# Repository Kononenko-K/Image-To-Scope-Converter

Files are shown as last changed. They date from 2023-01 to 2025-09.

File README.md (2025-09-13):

# Image-To-Scope-Converter
Raster oscilloscope image generator from an arbitrary bitmap file.
<br/>
<p align="center">
     
</p>

## Overview
The idea behind this project is based on the fact that rapid signal transitions are almost imperceptible on a CRT. Thus, if we make a signal jump with a very short rise/fall time from point A to point B, there will be no visible trace of movement on the display. Here, I use the MCU's DAC to generate horizontal and vertical scan signals, and an open-drain GPIO output to create the sharpest possible edge by shorting the DAC output to ground (which is not ideal, but the DAC's output impedance is relatively high anyway). This allows to return the dot on the screen to the zero position when the pixel is white, enabling the display of a raster image on any 2-channel CRT oscilloscope in XY mode without modifying its circuitry for brightness modulation.

## [Hardware](Hardware)
<p align="center">
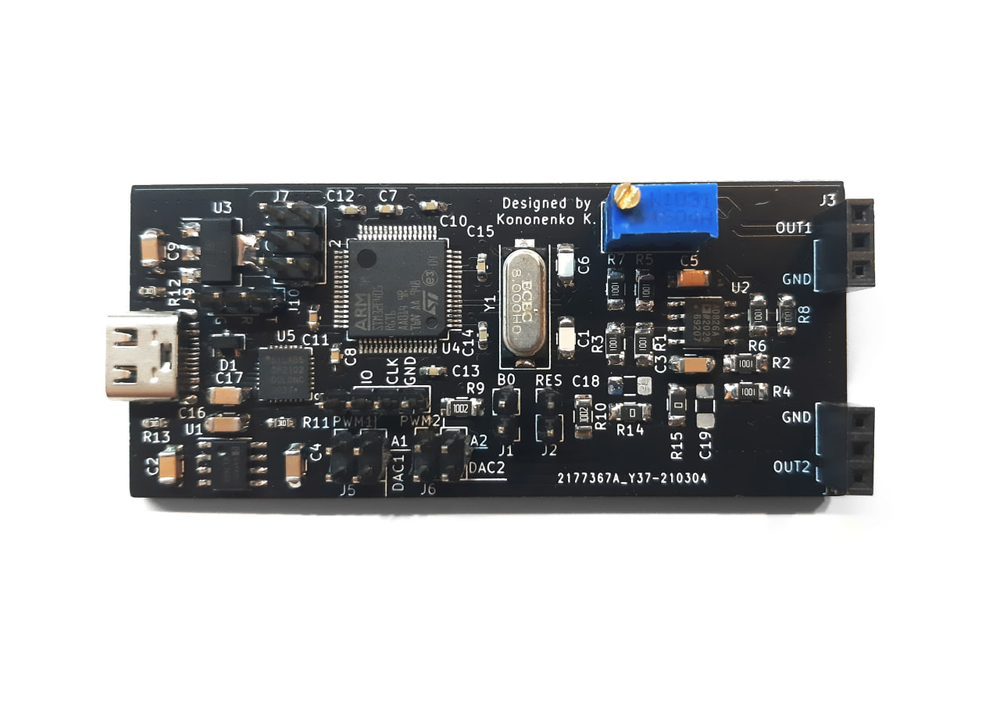
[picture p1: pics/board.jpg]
    
</p>

The board features an STM32F405 series MCU, USB-UART converter, USB Type-C connector, negative voltage generator, and a wideband 2-channel operational amplifier. [KiCad project files](/Hardware/PCB) and [PDF documentation](/Hardware/PCB/project.pdf) are avaliable. For correct operation, DACx and PWMx outputs should both be connected to the corresponding Ax pins.

## [Firmware](Firmware)
The firmware is configured to work with a 1 MBd USART speed, 256×256 image resolution, and adjustable frame rate. The MCU receives an 8192-byte array representing XBM-format images with 1 bit per pixel encoding. The frame rate can be adjusted using the button connected to the PB1 pin. A test image is included in the firmware and can be found in [test_im.h](/Firmware/Core/Src/test_im.h). It is displayed immediately after power-on until another image is loaded via UART.
The project is developed using STM32CubeIDE with HAL.

## [Software](Software)
<p align="center">
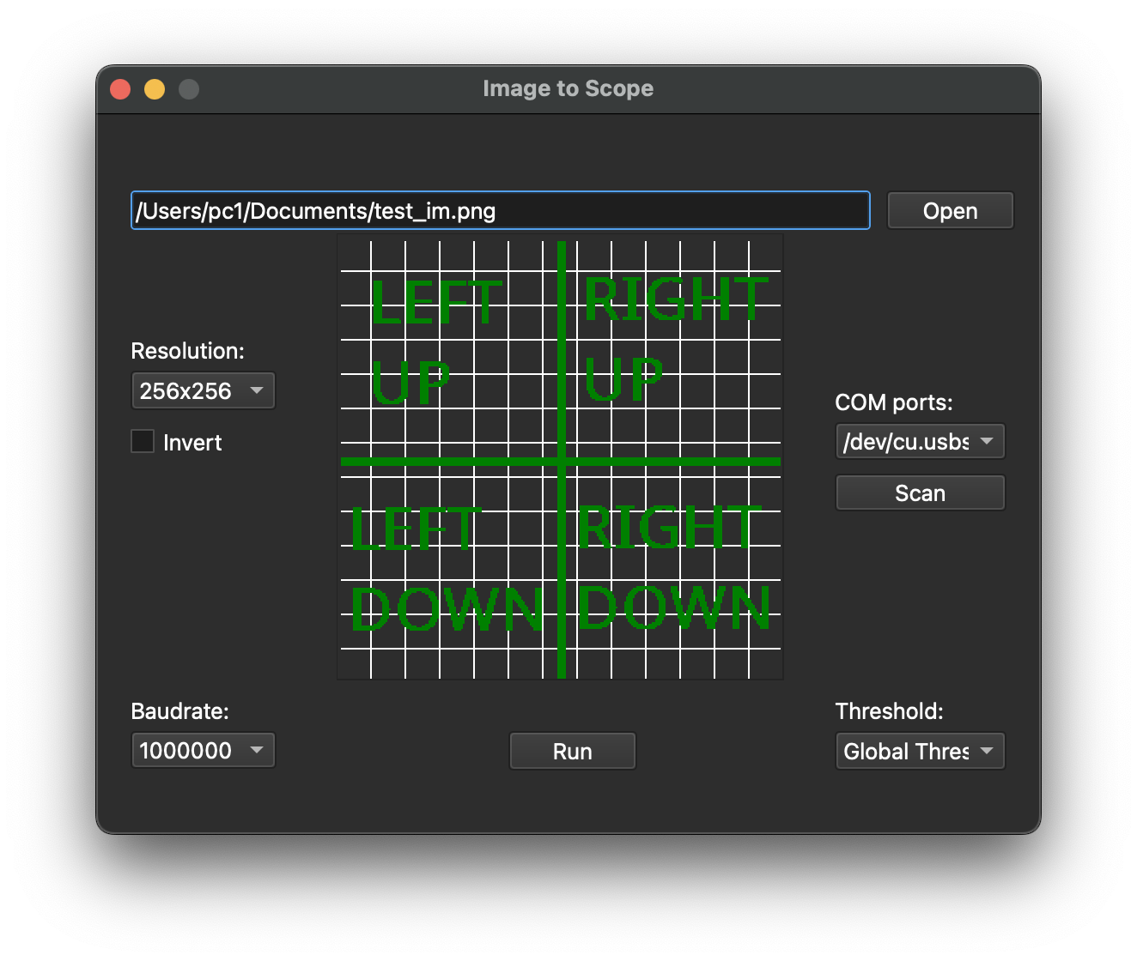
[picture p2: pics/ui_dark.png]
    
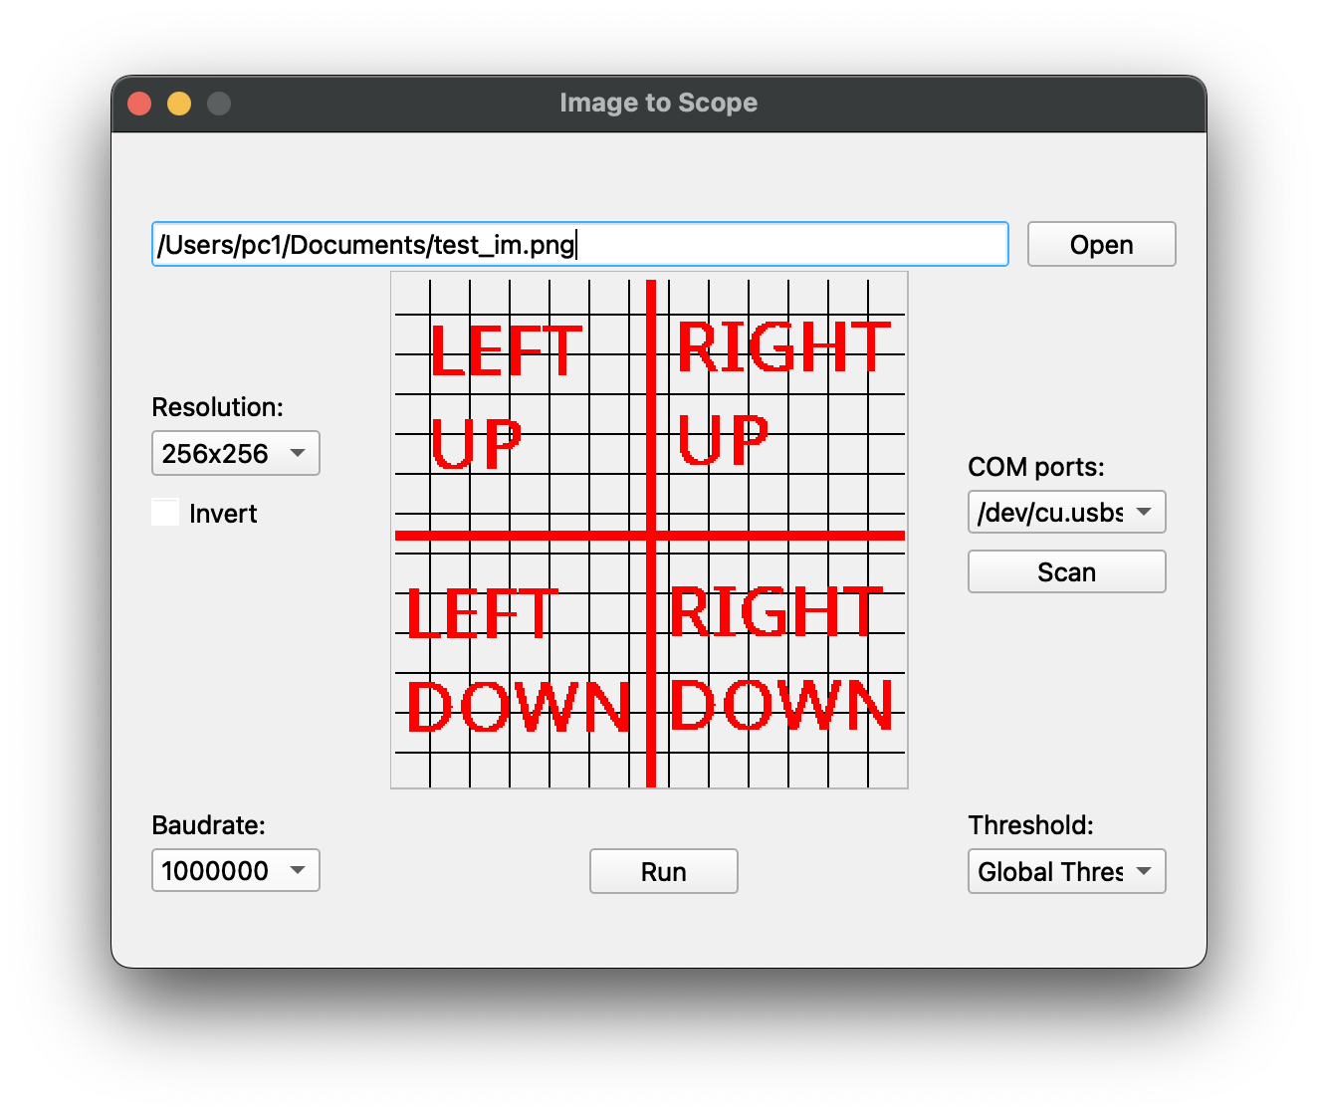
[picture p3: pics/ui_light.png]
    
</p>

I developed a Python PyQt6 script for the project GUI that generates properly formatted data from arbitrary images. Here are the [source code](/Software/ui.py) and [requirements](/Software/requirements.txt).

## [Enclosure](/Hardware/Enclosure)
<p align="center">
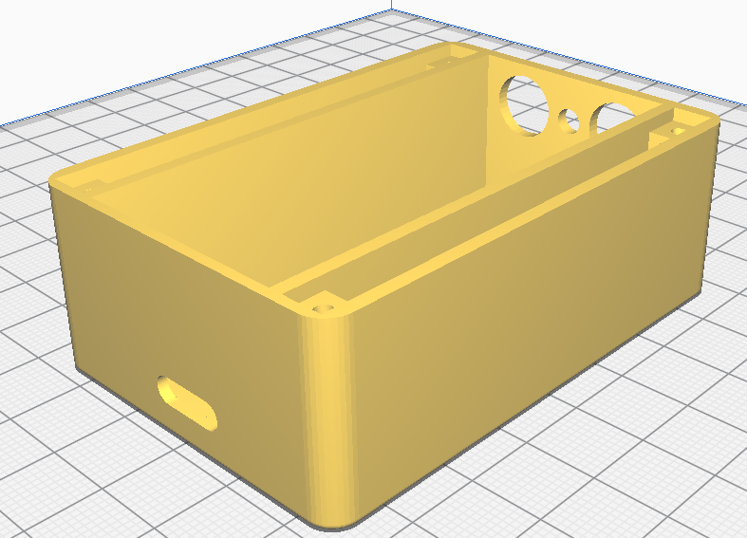
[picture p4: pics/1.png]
    
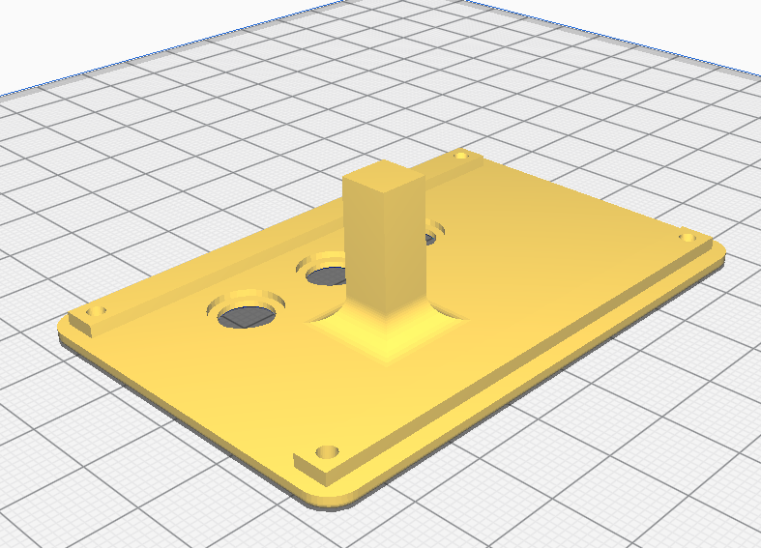
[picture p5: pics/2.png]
    
</p>

STL files for the [case](/Hardware/Enclosure/1.stl) and its [cover](/Hardware/Enclosure/2.stl) for 3D printing.

## License
- The **Software** and **Firmware** in this project are licensed under the [MIT License](/Firmware/LICENSE), with the exception of portions of the firmware code that are copyrighted by STMicroelectronics; such portions are subject to the original licensing terms provided by STMicroelectronics.
- The **Hardware** in this project is licensed under the [CERN Open Hardware Licence Permissive (CERN OHL-P)](/Hardware/LICENSE).

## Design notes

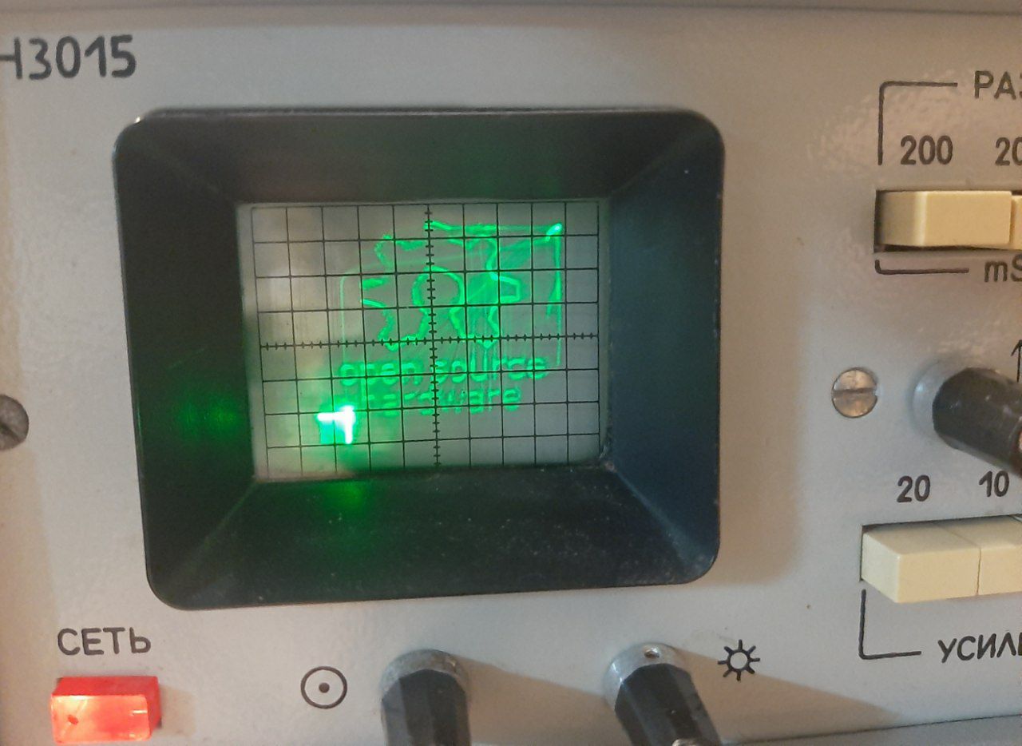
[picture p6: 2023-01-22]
pics/scope.jpg

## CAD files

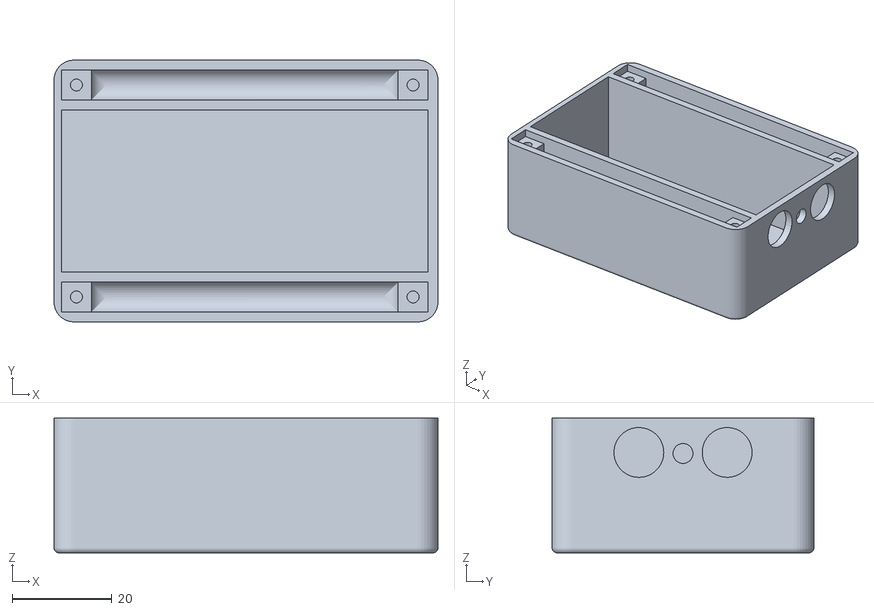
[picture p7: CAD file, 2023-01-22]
Hardware/Enclosure/1.stl
77.0 x 52.5 x 27.0

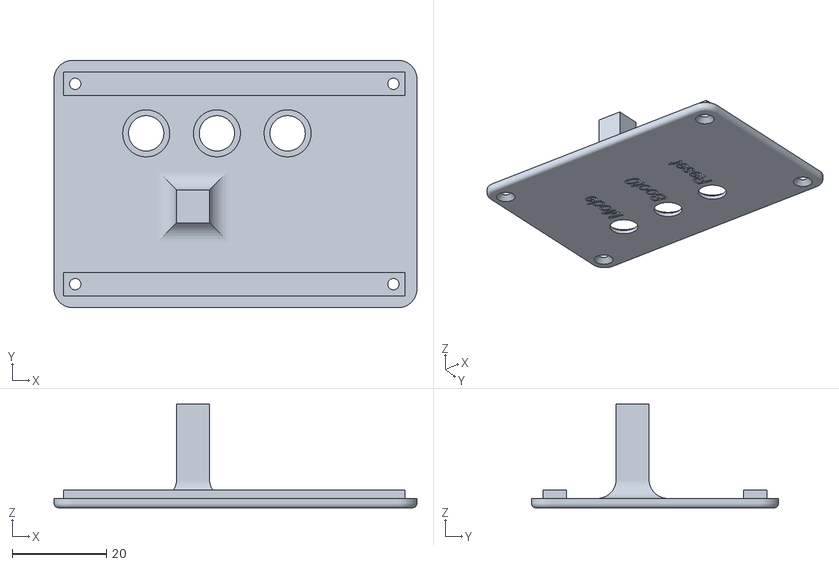
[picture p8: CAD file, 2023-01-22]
Hardware/Enclosure/2.stl
77.0 x 52.5 x 22.0

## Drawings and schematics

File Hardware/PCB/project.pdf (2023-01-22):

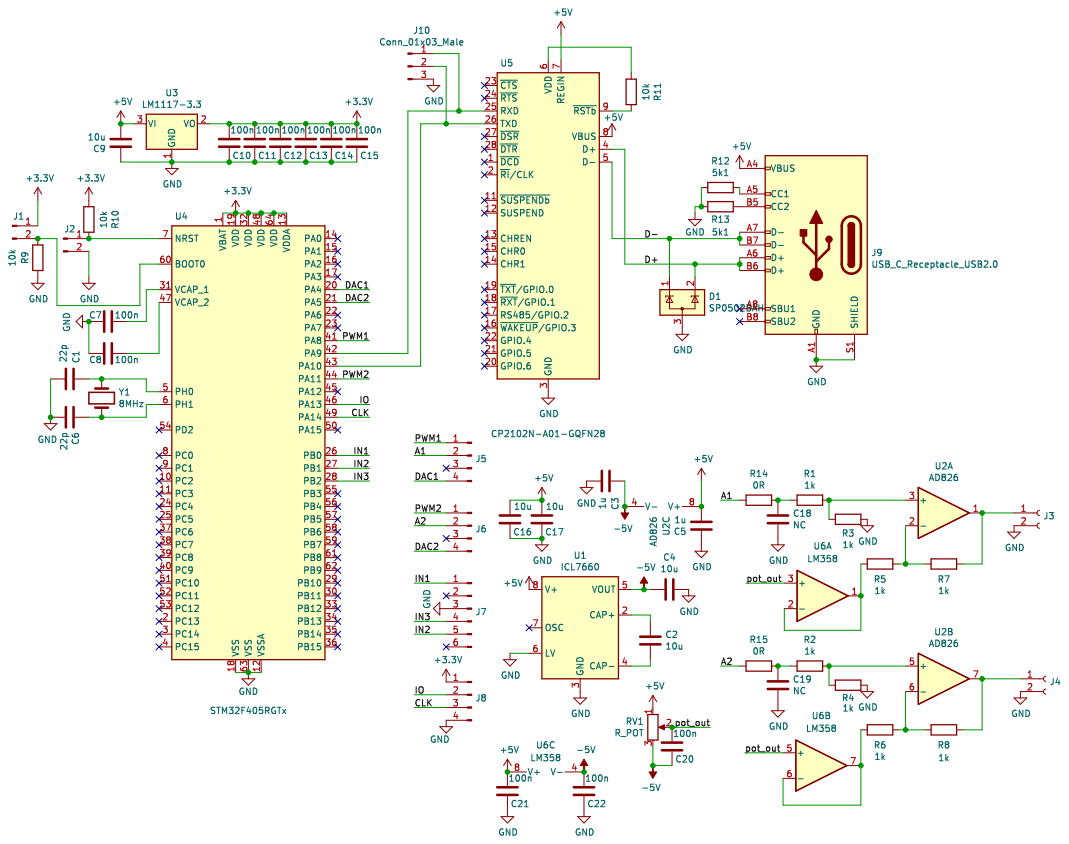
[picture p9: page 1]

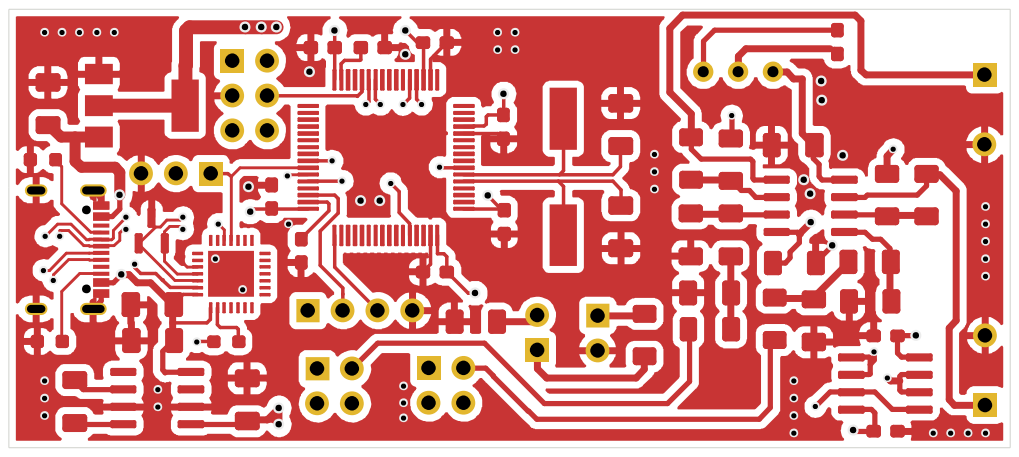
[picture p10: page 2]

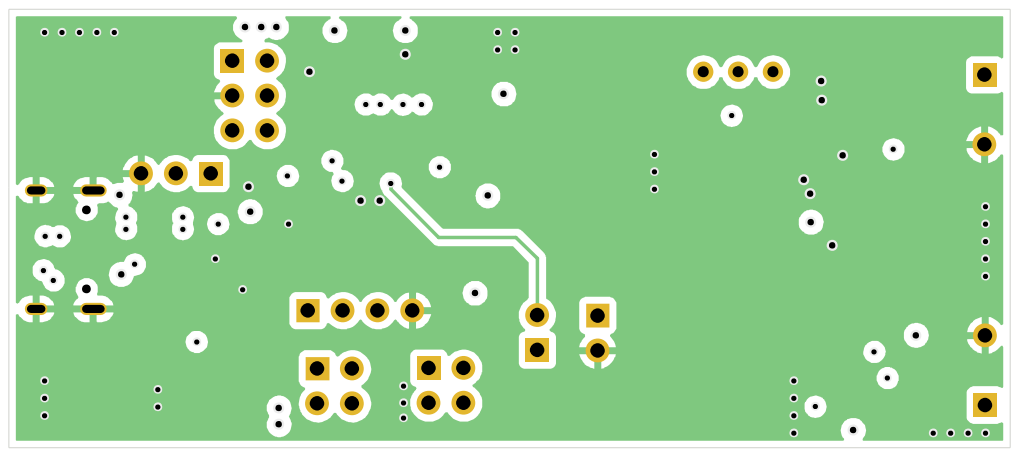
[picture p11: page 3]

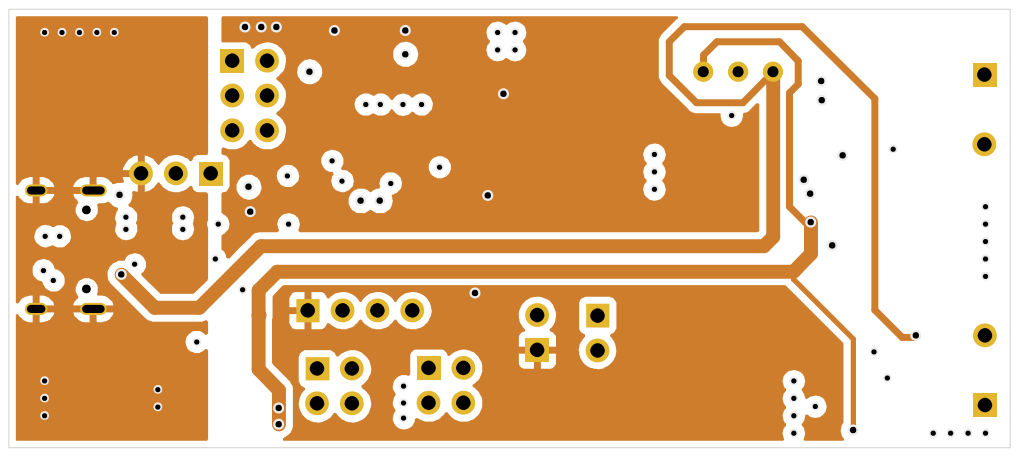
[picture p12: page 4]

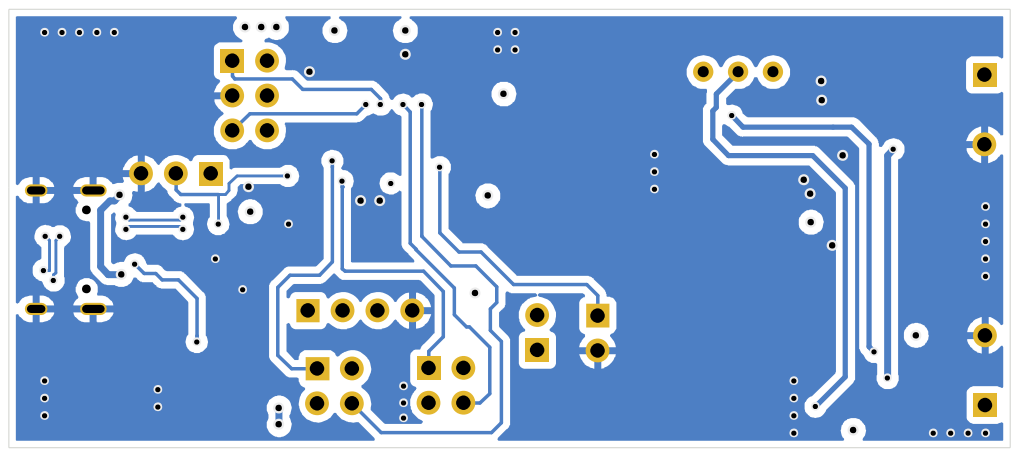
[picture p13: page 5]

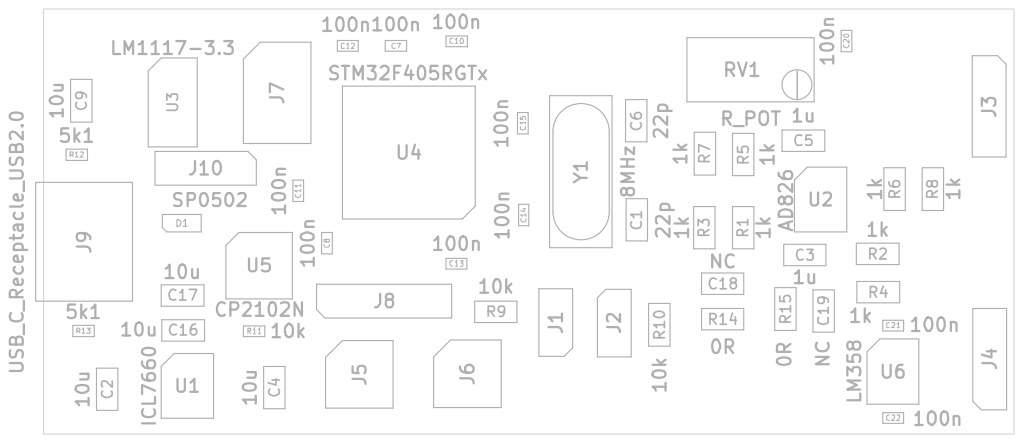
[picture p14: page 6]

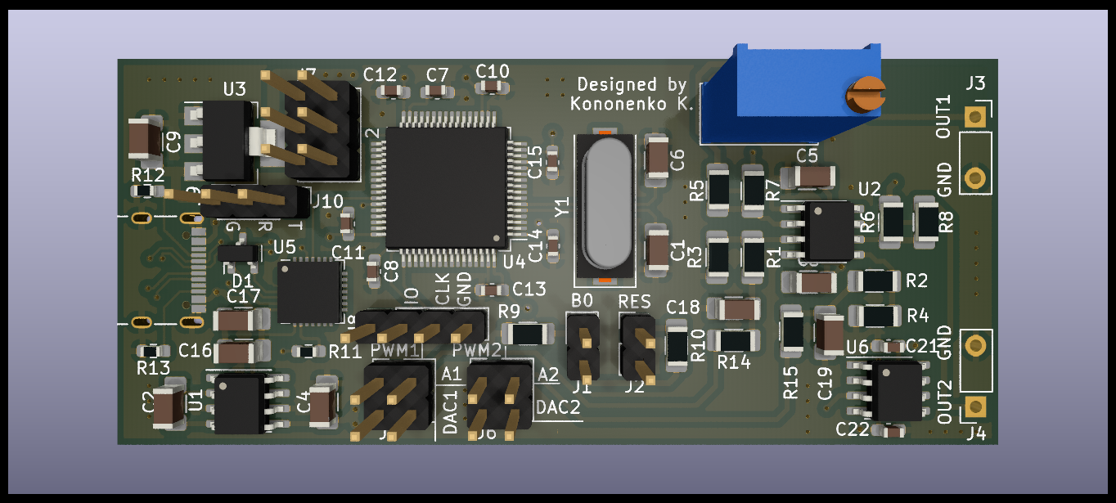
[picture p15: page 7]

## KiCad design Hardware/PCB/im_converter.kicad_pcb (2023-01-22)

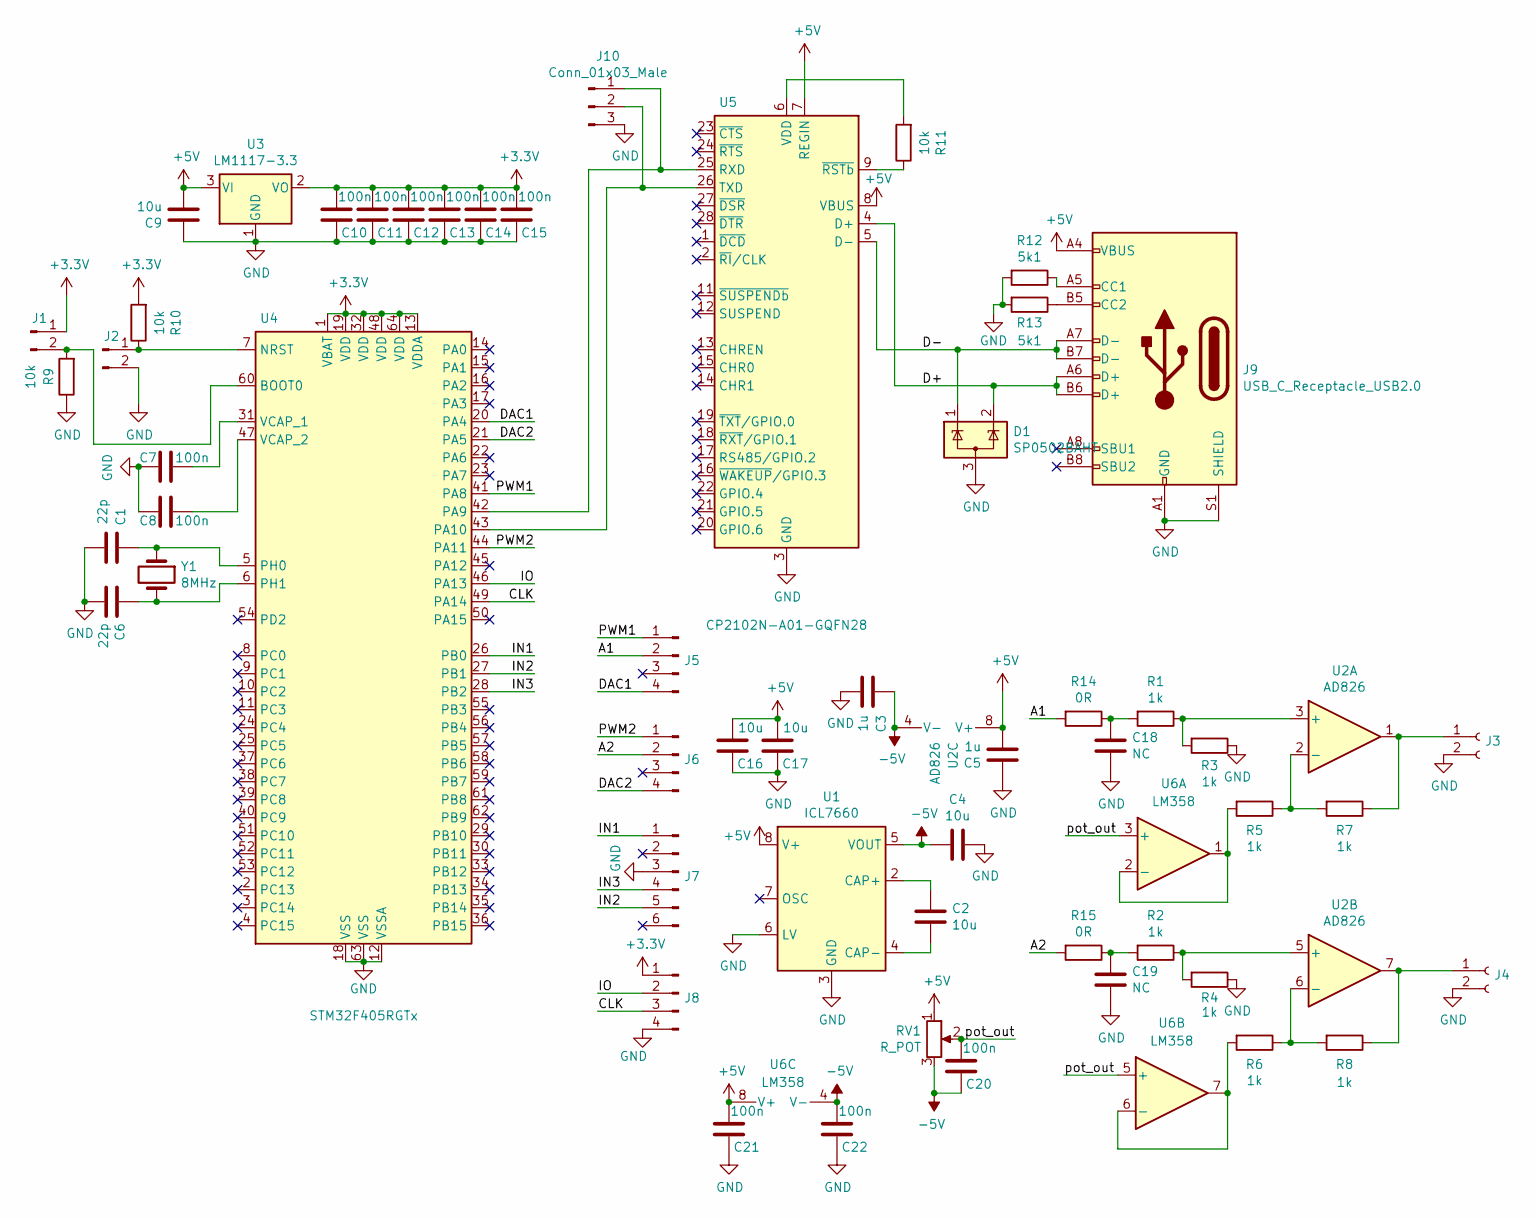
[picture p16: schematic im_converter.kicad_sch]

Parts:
C1, C6: 22p; C_1206_3216Metric_Pad1.33x1.80mm_HandSolder
C2, C4, C9, C16, C17: 10u; C_1206_3216Metric_Pad1.33x1.80mm_HandSolder
C3, C5: 1u; C_1206_3216Metric_Pad1.33x1.80mm_HandSolder
C7, C8, C10, C11, C12, C13, C14, C15, C20, C21, C22: 100n; C_0603_1608Metric_Pad1.08x0.95mm_HandSolder
C18, C19: NC; C_1206_3216Metric_Pad1.33x1.80mm_HandSolder
D1: SP0502BAHT; SOT-23
J1, J2: Conn_01x02_Male; PinHeader_1x02_P2.54mm_Vertical
J3, J4: Conn_01x02_Female; PinSocket_1x03_P2.54mm_Vertical
J5, J6: Conn_01x04_Male; PinHeader_2x02_P2.54mm_Vertical
J7: Conn_01x06_Male; PinHeader_2x03_P2.54mm_Vertical
J8: Conn_01x04_Male; PinHeader_1x04_P2.54mm_Vertical
J9: USB_C_Receptacle_USB2.0; USB_C_Receptacle_Palconn_UTC16-G
J10: Conn_01x03_Male; PinHeader_1x03_P2.54mm_Vertical
R1, R2, R3, R4, R5, R6, R7, R8: 1k; R_1206_3216Metric_Pad1.30x1.75mm_HandSolder
R9, R10: 10k; R_1206_3216Metric_Pad1.30x1.75mm_HandSolder
R11: 10k; R_0603_1608Metric_Pad0.98x0.95mm_HandSolder
R12, R13: 5k1; R_0603_1608Metric_Pad0.98x0.95mm_HandSolder
R14, R15: 0R; R_1206_3216Metric_Pad1.30x1.75mm_HandSolder
RV1: R_POT; Potentiometer_Bourns_3296W_Vertical
U1: ICL7660; SOIC-8_3.9x4.9mm_P1.27mm
U2: AD826; SOIC-8_3.9x4.9mm_P1.27mm
U3: LM1117-3.3; SOT-223-3_TabPin2
U4: STM32F405RGTx; LQFP-64_10x10mm_P0.5mm
U5: CP2102N-A01-GQFN28; QFN-28-1EP_5x5mm_P0.5mm_EP3.35x3.35mm
U6: LM358; SOIC-8_3.9x4.9mm_P1.27mm
Y1: 8MHz; Crystal_SMD_HC49-SD

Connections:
+3V3: C10.2, C11.2, C12.2, C13.2, C14.2, C15.2, J1.1, J8.1, R10.2, U3.2 (VO), U4.1 (VBAT), U4.13 (VDDA), U4.19 (VDD), U4.32 (VDD), U4.48 (VDD), U4.64 (VDD)
+5V: C5.2, C9.2, C16.2, C17.2, C21.2, J9.A4 (VBUS), J9.A9 (VBUS), J9.B4 (VBUS), J9.B9 (VBUS), RV1.1, U1.8 (V+), U2.8 (V+), U3.3 (VI), U5.7 (REGIN), U5.8 (VBUS), U6.8 (V+)
-5V: C3.1, C4.2, C20.1, C22.2, RV1.3, U1.5 (VOUT), U2.4 (V-), U6.4 (V-)
/A1: J5.2, R14.2
/A2: J6.2, R15.2
/CLK: J8.3, U4.49 (PA14)
/D+: D1.2 (K), J9.A6 (D+), J9.B6 (D+), U5.4 (D+)
/D-: D1.1 (K), J9.A7 (D-), J9.B7 (D-), U5.5 (D-)
/DAC1: J5.4, U4.20 (PA4)
/DAC2: J6.4, U4.21 (PA5)
/IN1: J7.1, U4.26 (PB0)
/IN2: J7.5, U4.27 (PB1)
/IN3: J7.4, U4.28 (PB2)
/IO: J8.2, U4.46 (PA13)
/PWM1: J5.1, U4.41 (PA8)
/PWM2: J6.1, U4.44 (PA11)
/pot_out: C20.2, RV1.2, U6.3 (+), U6.5 (+)
GND: C1.2, C3.2, C4.1, C5.1, C6.2, C7.2, C8.2, C9.1, C10.1, C11.1, C12.1, C13.1, C14.1, C15.1, C16.1, C17.1, C18.2, C19.2, C21.1, C22.1, D1.3 (A), J2.2, J3.2, J4.2, J7.3, J8.4, J9.A1 (GND), J9.A12 (GND), J9.B1 (GND), J9.B12 (GND), J9.S1 (SHIELD), J10.3, R3.1, R4.1, R9.1, R12.2, R13.2, U1.3 (GND), U1.6 (LV), U3.1 (GND), U4.12 (VSSA), U4.18 (VSS), U4.63 (VSS), U5.3 (GND), U5.29 (GND)
unnamed: C1.1, U4.5 (PH0), Y1.1
unnamed: C2.1, U1.2 (CAP+)
unnamed: C2.2, U1.4 (CAP-)
unnamed: C6.1, U4.6 (PH1), Y1.2
unnamed: C7.1, U4.31 (VCAP_1)
unnamed: C8.1, U4.47 (VCAP_2)
unnamed: C18.1, R1.2, R14.1
unnamed: C19.1, R2.2, R15.1
unnamed: J1.2, R9.2, U4.60 (BOOT0)
unnamed: J2.1, R10.1, U4.7 (NRST)
unnamed: J3.1, R7.1, U2.1
unnamed: J4.1, R8.1, U2.7
unnamed: J9.A5 (CC1), R12.1
unnamed: J9.B5 (CC2), R13.1
unnamed: J10.1, U4.42 (PA9), U5.25 (RXD)
unnamed: J10.2, U4.43 (PA10), U5.26 (TXD)
unnamed: R1.1, R3.2, U2.3 (+)
unnamed: R2.1, R4.2, U2.5 (+)
unnamed: R5.1, R7.2, U2.2 (-)
unnamed: R5.2, U6.1, U6.2 (-)
unnamed: R6.1, R8.2, U2.6 (-)
unnamed: R6.2, U6.6 (-), U6.7
unnamed: R11.1, U5.9 (~RSTb)
unnamed: R11.2, U5.6 (VDD)

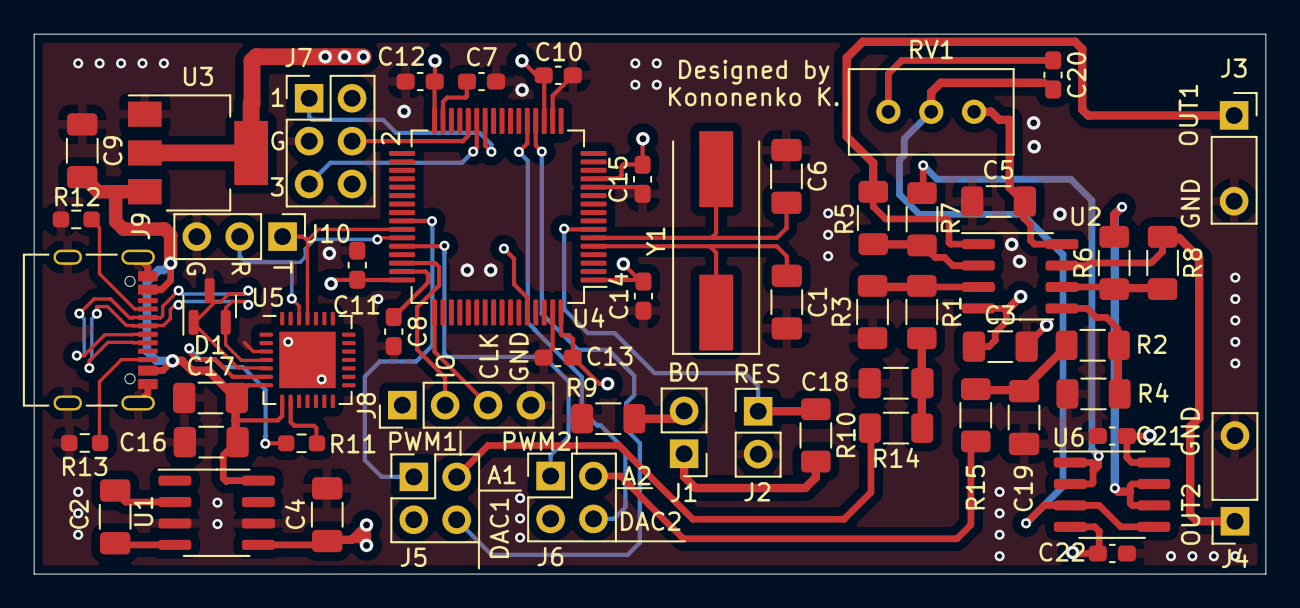
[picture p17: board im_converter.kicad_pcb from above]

Board: 4 copper layers, 73.0 x 32.0 mm, 56 parts (0 on the bottom side), 42 nets.

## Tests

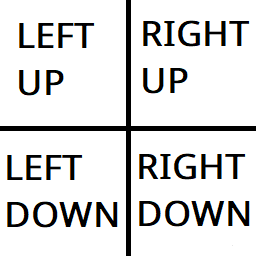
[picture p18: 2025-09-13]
Software/input_pics/test_im.png

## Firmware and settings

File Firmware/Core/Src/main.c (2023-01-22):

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
/* Includes ------------------------------------------------------------------*/
#include "main.h"

/* USER CODE BEGIN Includes */
#include "test_im.h"
/* USER CODE END Includes */

/* USER CODE BEGIN PD */
#define BUFSIZE 8192
#define INIT_PRESC 115
#define DECR_PRESC 15
/* USER CODE END PD */

DAC_HandleTypeDef hdac;

TIM_HandleTypeDef htim1;
TIM_HandleTypeDef htim2;
TIM_HandleTypeDef htim3;

UART_HandleTypeDef huart1;

/* USER CODE BEGIN PV */
//extern static uint8_t test_im[];
uint8_t buff[BUFSIZE] = {0,};
uint8_t v = 0;
uint8_t presc1 = INIT_PRESC;
/* USER CODE END PV */

void SystemClock_Config(void);
static void MX_GPIO_Init(void);
static void MX_TIM1_Init(void);
static void MX_USART1_UART_Init(void);
static void MX_DAC_Init(void);
static void MX_TIM3_Init(void);
static void MX_TIM2_Init(void);
/**
  * @brief  The application entry point.
  * @retval int
  */
int main(void)
{
  /* MCU Configuration--------------------------------------------------------*/

  /* Reset of all peripherals, Initializes the Flash interface and the Systick. */
  HAL_Init();

  /* Configure the system clock */
  SystemClock_Config();

  /* Initialize all configured peripherals */
  MX_GPIO_Init();
  MX_TIM1_Init();
  MX_USART1_UART_Init();
  MX_DAC_Init();
  MX_TIM3_Init();
  MX_TIM2_Init();
  /* USER CODE BEGIN 2 */

  HAL_TIM_Base_Start_IT(&htim2);
  HAL_DAC_Start(&hdac,DAC_CHANNEL_1);
  HAL_DAC_Start(&hdac,DAC_CHANNEL_2);
  TIM3->CCR4=127;
  TIM2->PSC = presc1;
  for (int i = 0; i < 8192; i++) {
	  buff[i] = test_im[i];
  }

  /* USER CODE END 2 */

  /* Infinite loop */
  /* USER CODE BEGIN WHILE */
  while (1)
  {
	HAL_UART_Receive_IT(&huart1, (uint8_t*)buff, BUFSIZE);

	DAC->DHR12R1 = v*16;
	DAC->DHR12R2 = (TIM2->CNT)*16;
	uint8_t bit_counter = (TIM2->CNT)%8;
	uint8_t byte_counter = (TIM2->CNT)/8;
	if ((buff[v*32+byte_counter]>>bit_counter)%2) {
		GPIOA->ODR |= (1<<8);
		GPIOA->ODR |= (1<<11);
	}
	else {
		GPIOA->ODR &= ~(1<<8);
		GPIOA->ODR &= ~(1<<11);
	}

	if (HAL_GPIO_ReadPin (GPIOB, GPIO_PIN_2) == 0) {
		presc1 -= DECR_PRESC;
		TIM2->PSC = presc1;
		HAL_Delay(200);
	}


    /* USER CODE END WHILE */

    /* USER CODE BEGIN 3 */
  }
  /* USER CODE END 3 */
}

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


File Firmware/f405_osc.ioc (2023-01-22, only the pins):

Mcu.UserName=STM32F405RGTx
PA10.Signal=USART1_RX
PA11.Signal=GPIO_Output
PA13.Signal=SYS_JTMS-SWDIO
PA14.Signal=SYS_JTCK-SWCLK
PA4.Signal=COMP_DAC1_group
PA5.Signal=COMP_DAC2_group
PA8.Signal=GPIO_Output
PA9.Signal=USART1_TX
PB2.Signal=GPIO_Input
PH0-OSC_IN.Signal=RCC_OSC_IN
PH1-OSC_OUT.Signal=RCC_OSC_OUT

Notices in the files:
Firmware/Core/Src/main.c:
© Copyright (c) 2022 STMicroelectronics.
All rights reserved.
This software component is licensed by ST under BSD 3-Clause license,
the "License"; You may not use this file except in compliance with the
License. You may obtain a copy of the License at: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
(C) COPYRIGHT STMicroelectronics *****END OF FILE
